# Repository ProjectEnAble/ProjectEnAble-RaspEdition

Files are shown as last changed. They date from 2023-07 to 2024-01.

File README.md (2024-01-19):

# Project: EnAble RPi Edition
   

# Releases 
|Version | Supported |
| --- | --- |
| v4 | IN DEV |
| v3.1.0 - Beta | :white_check_mark: |

# About
Project: EnAble is an open source prosthetic system and design created by Jeron Osguthorpe with hopes to help make the world more accessible. Project: EnAble uses a series of sensors, motors and micro computers (either RPi or Arduino) in order to control customizable
prosthetic devices. Learn more at [projectenable.org](http://projectenable.org).

# CHANGE LOGS

8.30.21 <br>
index.py is created to test the touch sensors. The touch sensors were purchased off of Amazon for 10 of them for about $8. The serial number for the sensors is TTP223 Sensor Module. The sensor module successfully works with the Raspbery Pi 3B+ 

8.31.21 <br>
motors.py, microbit.py, motorspy2.py files were all crated to test certain funciton (look in directory). Remington came over to help program the sensors and the motors. Before he came over, I got all the sensors working and got it so that if the sensor goes off the motors move. We changed it with the help of Rem to make it so that it is now when the sensor is pressed the motor stops. All of this  is contained in motorspy2.py. We are trying to make it so that and "or" statement inside a while statement works. 

9.1.21 <br>
motorspy2.py alteration. Fixed the problem with getting both the sensors to stop the motor. Did this by changing it form an "or" statement to an "and" statement. For some reason, this works.

9.2.21 <br>
Today we had science research because it is a Thurday. I realized in class that I only have 26 avaiable pins for the sensors and the motors at the same time. So I decided to put two sensors into one pin becasue as long as it can send an input to the raspberry pi, it should work. I have decided that I am just going to stick with the Raspberry Pi an the Micro:bit because I really don't want to have to convert everything from Python into Micro:Python becasue honestly that is just a pain. Everthing has been assigned its new pins and they are all contained inside of the new file that I made.

9.2.21 <br>
fixed a couple of spelling mistakes in README.MD. I did this mostly to see if I can use git and github correctly, before I make any big changes to the code.

9.2.21 <br>
Just barely added a bunch of Micro:Bit Serial codes. Here is the list 
Shake = 1 
Logo up = 2
Logo Down = 3
Screen Down = 4
Screen Up = 5
Tilt Left = 6
Tilt Right = 7
Freefall = 8
3G = 9
6G = 10
8G = 11 
A = 12
B = 13 
AB = 14 

12.14.2021 <br>
Changed the motors around in the code and fixed the sleep problem. The entire hand is now assembled, Just have to figure out where I want to put the motors. Other than that the project is pretty much done. It is supposed to be done by 12.16.2021...so I really need to hurry, but it should be all fine. Hopefully Rem can fix the code and get it to me soon. I also uploaded a "main.py" this is now the new main file. 

6.18.2022 <br>
As of June 18th of 2022, this is the final last edit of Project: EnAble v2.0. Project: EnAble v3.0 will now commence including the new forms for the science fairs that the project will be competing in, including the many different forms of the project. Past versions will be avaible in their respective folders. Thanks to everyone who was and is supporting me with this project, we ended up winning First Place in our local science fair, The Air Force award as well as the chance to go to Atlanta, Georgia for the International Science and Engineering Fair (ISEF 2022)!  

6.18.2022 - B <br>
As of June 18th of 2022, the forms for the 2023 year of the project have now been uploaded. The project goes from May 16th 2022 to whenever finished (must be before May 16th 2023). The research plan has also been uploaded for the 2023 project. The 2023 project is refered to as Project: EnAble v3.0. The number after the decimal will change later on in version notes, but the overall project for the year will be refereed to as "Project: EnAble v3.0". The project this year has now been completely opened up to OPEN SOURCE. Anyone can use the files within this project as long as they are following the licenses provided (see LICENCES). All forms and information regarding v1.0 are under the year "2021" however, the files are missing. This project is competing for the International Science and Engineering Fair under Jeron Osguthorpe. Please see more info under v3.0 release notes when it is released. License notes have been updated for the 2023 year. "Project: EnAble is officially licensed with Copyright under the "GNU LESSER GENERAL PUBLIC LICENSE Version 2.1"

6.19.2022 <br>
As of June 19th of 2022, Project: EnAble v3.0 has started production. See the todo list in the "Projects" tab to see what we are doing for Project: EnAble v3.0 at the moment. 

7.24.2022 <br>
Been a while since we have updated the chagne logs. As of right now, we are in the 3D design and printing of the development of Project: EnAble v3.0. Soon hereafter we will have the Gauntlet finished. After that, we will work on the development of the palm, and then the fingers. The Philanges being used this year are going to be an altered design of the philagnes used in the Cyborg Arm by Creighton University, also the philagnes used in v2.0 of Project: EnAble. Hopefully, we will be able to get the Raspberry Pi version of everything up and printed. The only deifference between the Raspberry Pi version and the Arduino version in terms of the phiscial 3D Printed hand, is the Gauntlet. The Gauntlet will be accomondated for the Arduino, however, should not look much different. Thanks for all your support, it is greatly appreciated. Check out our twitter account at http://twitter.com/proj_enable and at our Webstie at http://projectenable.org. To give suggestions, ask questions or anything else, please check our discussions page or email me at jeronosg@outlook.com. If you would like to donate, please see our donations links. If you would like to see how far we are in development, please see our projects page. Again, thanks, and we will keep you updated. 

8.15.2022 <br>
Development of 3D Designs for a Hand for the Project:EnAble v3.0 open source system is on pause. However, development of the Program of Project:EnAble v3.0 has now started and should have the main release finished in a week or so for Raspberry Pi. Development for Arduino version has not started yet. Check out the discusssion and projects tab for more information. 

9.14.2022 <br>
Development has continued. At the moment, basic bugs in the "v3.0" file in the Beta version of Project: EnAble v3.0 have been fixed. Development will stay on pause with code for the next big while I once again, continue to work on the design of the hand. The two main designs that I am having trouble with are the Gauntlet, and the Palm. If you have any suggessions of what I can do with anything, please either message me, visit the discussions tab, make an issue, or tag me on twitter. Thanks. 

9.16.2022 - A <br>
Development of Project: EnAble v3.0.02 - BETA has begun. Sadly, the continuation of the design of the gauntlet has not. I should be getting to that later (as in later today). Project: EnAble v3.0.02 - BETA and above will be using a licensing service offered by Cryptolens. Becasue our project aims to be affordable and open source, the licenses will be free. You will have to request a license however in order to use the program. This is to try to eliminate as much piracy as possible. I am aware that there are ways to get around this by editing the code, I at this point in time am just going to trust the honor system with how far we are with the project. You guys are the best and thank you so much for your suport and your understanding. Let me know if you have any questions, comments, concerns or anything else. 

9.16.2022 - B
Created information.md. information.md gives basic information while programing, such as Micro:Bit information, as well as how to change the project to work with different prosthetics. I also made edits to v3.0.py, making it a bit more cleaned up and organzied. Updated SECURITY.md.

9.17.2022 - 9.18.2022<br>
Updated v3.0.py. Made changes concerning the functions for shaking someones hand and/or canceling the functions. Updated the gauntlet making changes that will fix multiple measurement errors. Also made a YT video containing everything that is/will be new with v3.0.02/03. You can find said video [here](https://youtu.be/PkbhiCFiDQM).

12.10.2022<br>
I know that it has been a while since I have updated this. I apologize for that. In terms of official releases on the project, you can see more in the project history. You can also find out more by visiting our [Twitter Page](http://twitter.com/Proj_EnAble).

1.23.2023<br>
As of today, v3.0.03-BETA is released along side the [YouTube Video](https://www.youtube.com/watch?v=dp4VP448C9U). This is the final BETA release of Project: EnAble v3.0 before the official release. The official release will be released towards the end of Febuary to the beginning of March. If you have any questions, comments or concersn please see the contact information above. If you would like ot know more of Project: EnAble v3.0.03-BETA see the the release under "RELEASES". Thanks for all your support.

3.7.2023<br>
As of today, v3.0.0 is released. This is the official release of Project: EnAble v3.0. If you have any questions, comments or concersn please see the contact information above. If you would like ot know more of Project: EnAble v3.0.0 see the the release under "RELEASES". Thanks for all your support.

5.4.2023 <br>
Bluetooth Support is now added! Now you can use the official Android Project: EnAble app (releasing in late May 2023), to control the sensitivity of the prosthetic devies(s). *NOTE: This is only for Raspberry Pi Edition*. Setting up bluetooth suppport can be found in the information.md file. This contains all the information you need to set up your device. The official Android app will be relased along with Project: EnAble v3.1.0 - Beta in late May of 2023. Expect some crazy new featuers as well as custom sensitivity and user profiles! If you would like to learn more of how this was created, check out the YouTube Channel [Coding Tricks](http://youtube.com/codingtricks). Thank you all for your support!  

6.7.2023<br>
Update on everything. We will be presenting at a tech conference in Chicago in late June. For this tech conference we will be presenting the Arduino v3.1.0 - Beta version of the project. As of today, this version has not been officially released, but it will be in the upcoming weeks. 

7.10.2023<br>
Update again. Chicago was a success! Thank you to all those who have been supporting me and the project thorugh this journey! I am happy to announcethat we will be changing the repositories for the project up a bit. Releasing later today will be two different repositories, one of which will be the Raspberry Pi repository (releasing with v3.1.0 - Beta), and the other will be the Arduino repository (releasing with v3.1.0a - Beta). As with these versions, the official Android App for the Raspberry Pi version can be found at the official website, [projectenable.org](http://projectenable.org). Thanks again for all your support. 

7.10.2023 - B<br>
As another announcemnt, Project: EnAble v2.0 - Final is no longer supported and will be disapearing along with the old repository. 

1.18.2024 <br>
Hello everyone, we haven't updated the Change Logs in a while, so there are a few things that I would like to notify you all of. We are now going to be posting changes and updates on Project: EnAble on the official [website](http://projectenable.org) and the official [X/Twitter](http://twitter.com/proj_enable). We are not going to be updating the change logs here any more. There are a lot of changes in the making right now, and we are going to be updating the repositories in the next little bit. We are going to be redoing the entire README.md as well as introducing more upcoming features. For now, if you would like to stay updated with Project: EnAble, please visit the [official website](http://projectenable.org).

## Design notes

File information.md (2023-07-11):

# Extra Code Information for Project: EnAble v3.0

Here is some extra information about the code contained in v3.0.py. This is information such as [Micro:Bit](https://microbit.org) serial data code, and other related code. 

## Micro:Bit
### Serial Data Codes
B'1' = SHAKE

B'2' = LOGO UP

B'3' = LOGO DOWN

B'4' = SCREEN DOWN

B'5' = SCREEN UP

B'6' = TILT LEFT

B'7' = TILT RIGHT

B'8' = FREEFALL 

B'9' = 3G

B'10' = 6G 

B'11' = 8G

B'12' = BUTTON A

B'13' = BUTTON B

B'14' = BUTTONS AB 

## Connecting Pins
### Servo Motors
Index Finger: 5
Middle Finger: 6
Ring Finger: 13
Pinky Finger: 19
Thumb: 26

### FSR Sensors
CLK: 12
MISO: 16
MOSI: 20
CS: 21

## How to Change from Prostheic Hand, to some other Prosthetic Device
### Step 1
For those of you who are creating a prostheic deivce with the software based off Project: EnAble, this is how you would do this. You will want to make a fork of Project: EnAble off of the [GitHub Repository](http://github.com/projectenable/ProjectEnAble-RaspEdition). 

### Step 2
You will want to then ONLY ALTER v3.0.py. You will only alter information after the comment that says, "START OF CODE (CAN EDIT AS YOU WISH)". Because we use a Micro:Bit as our main sensor for the Raspberry Pi version of the project, we will be altering the functions based off the code. 

#### Step 2.1 - Importing Libraries
Make sure that you have all the libraries imported correctly for your project. You will most likely not need more than I have already provided. 

Some you may have to install onto the Raspberry Pi. You can do this by running the following commands: 
##### PIL/Pillow
`sudo apt-get install python3-pip`
`pip3 install pillow`

##### Touchscreen Libraries
`sudo rm -rf LCD-show`
`git clone https://github.com/goodtft/LCD-show.git`
`chmod -R 755 LCD-show`
`cd LCD-show/`
`sudo ./MPI3508-show`

##### Tkinter (may need)
`sudo apt-get install python3-tk`

#### Bluetooth Connectivity (for Project: EnAble Android Application) -- Upcoming Update

PAIR YOUR PHONE TO THE RASPBERRY PI AND DO THE FOLLOWING STEPS

`sudo bluetoothctl`
`connect PHONE_MAC_ADDRESS`
`trust PHONE_MAC_ADDRESS`

NOW EDIT THE FOLLOWING FILE

`sudo nano /lib/systemd/system/bluetooth.service`
add --compat to line "ExecStart=/usr/lib/bluetooth/bluetoothd" 

Should look like: "ExecStart=/usr/lib/bluetooth/bluetoothd --compat"

NOW RECONNECT THE PHONE TO THE RASPBERRY PI

DO THE FOLLOWING STEPS
`sudo nano /etc/rc.local`

Add `sudo rfcomm watch hci0` before the `exit 0` line 

** REBOOT ** 

NOW YOU MAY RUN `test_bluetooth.py` or `bluetooth.py`

As of right now, bluetooth is experimental, it does not seem to like to corroperate with the app, so we may need to give it it's own separate run file. It shouldn't be too difficult but as of right now we are focusing on other things.

##### Other Libraries Used (should already be preinstalled)
`import subprocess`
`from fileinput import close`
`import RPi.GPIO as GPIO`
`import time`
`from time import sleep`
`import os`
`import random`
`import serial`
`import bluetooth`

#### Step 2.2 - Importing Micro:Bit Serial Information
If you are simply connecting the Micro:Bit to the Raspberry Pi via. USB, you will not need to edit this area. Assuming you are running [Raspberry Pi OS](https://www.raspberrypi.com/software/). If you are running off of other software, the "z1port" may or may not need to be changed according to what port you connect. 

#### Step 2.3 - Setting Variables for Sensors and Motors
For this section, I have already entered the variables for pressure sensors for a prosthetic hand, servo motors for a prosthetic hand. If you are using servo motors, then you dont have to change anything else afterwards. If you ARE NOT using servo motors, then you can change the "SETUP SERVO MOTORS" section. 

Overall, you only need to edit the port numbers according to what you assign. This is what I have assigned. 

#### Step 2.4 - Sensitivity
This is a part that you will edit. If you are wanting multiple modes and need to ask the user for input, then you can edit this to the input that you want. 

NOTE! You can also assign buttons if you want to do this instead of asking for input from the user

#### 2.5 - Functions 
This is probably the part that you will alter the most. This is where you will change what happens based off your functions. In my project, I have 3 input modes, "Low, Medium, and High". For each one, I only change when the motors stop based off the amount of pressure gathered by the pressure sensors. If you are not using modes, then you wont need multiple functions. 

Each function does assignments based off the serial data gathered by the Micro:Bit. You will edit what the motors do based off the serial data that you choose. What you see is what I chose for a prosthetic hand. 

#### 2.6 - Calling the Program 
This is where I call the functions based off the sensitvity. If the user enters low, then run low... and so forth. 

If you are not using multiple modes, just call your function. 

### Step 3
Now that you have altered all your code to do what you would like. Please be sure that you a have a license key for the project. I know that this is annoying and that you wont want one, but they are completely free. This is just to avoid piracy of my program/project. Please be respectful of this. 

According to License Requirements, you must keep all the code together. This means, although you are allowed to edit what is in v3.0.py, you CANNOT delete any files or edit what is in other files. 

You must also state somewhere in your code, "Project: EnAble is under Copyright © 2023 Jeron Osguthorpe". I am going off the honor system, I have spent years on this project and I just am hoping that the development community will respect the work that I have done. 

## Prosthetic Hand - What I have Provided
If you are wanting to reporduce the prosthetic hand that I have created, then all the files needed are included. The 3D Printing files are including in the folder "v3.0 3D Files for Prosthetic Hand". All you will need is a License Key (email enable@codingtrickyt.com). 

## Other Information Regarding Project: EnAble
[GitHub Organization Link](http://github.com/projectenable) 

[GitHub Repository Link](http://github.com/projectenable/ProjectEnAble-RaspEdition)

[Project: EnAble Website](http:/projectenable.org)

Contact Email: enable@codingtricksyt.com

[YouTube](http://youtube.com/codingtricks)

[Twitter](http://twitter.com/proj_enable)

[License, Code of Conduct, and Contributing](http://github.com/projectenable/ProjectEnAble-RaspEdition)

[Donate](http://github.com/projectenable)

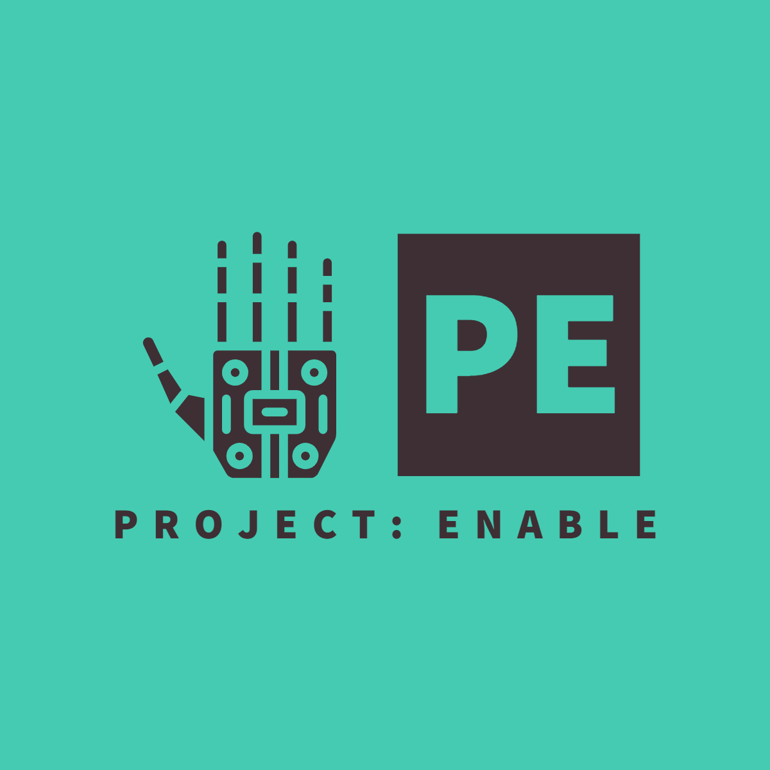
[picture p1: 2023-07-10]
v3.0/images/background.png

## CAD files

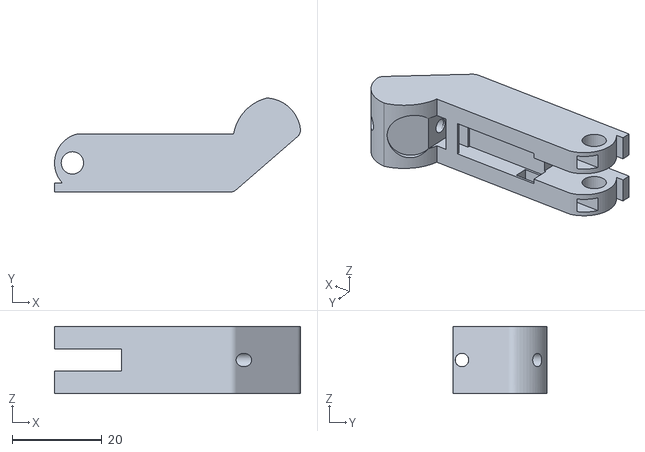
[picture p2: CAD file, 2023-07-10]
v3.0 3D Files for Prosthetic Hand/STL Files/ProjEnAble_Finger.stl
54.9 x 21.0 x 15.0

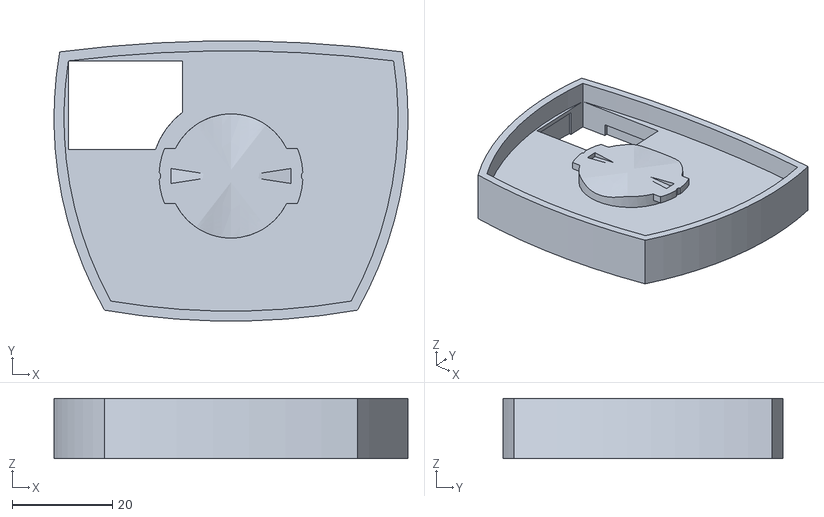
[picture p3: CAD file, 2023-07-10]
v3.0 3D Files for Prosthetic Hand/STL Files/ProjEnAble_MicroBit_Module testing.stl
70.7 x 55.9 x 12.0

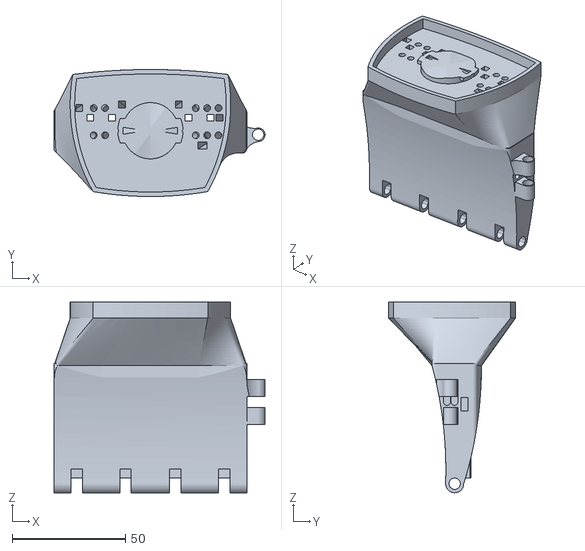
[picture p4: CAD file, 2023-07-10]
v3.0 3D Files for Prosthetic Hand/STL Files/ProjEnAble_Hand.stl
93.0 x 56.0 x 84.0

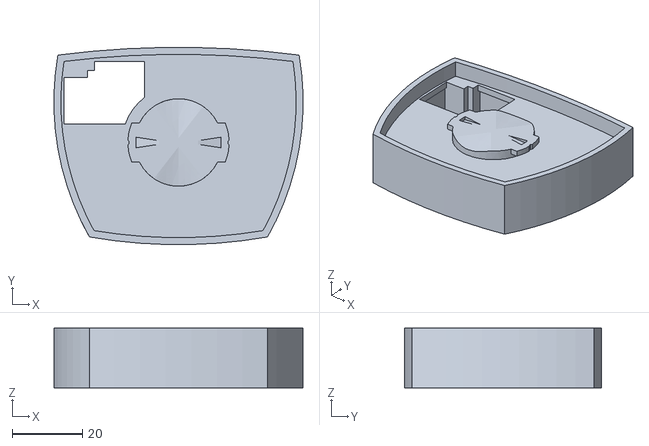
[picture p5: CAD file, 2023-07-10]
v3.0 3D Files for Prosthetic Hand/STL Files/ProjeEnAble_MicroBit_Module.stl
70.7 x 55.9 x 17.0

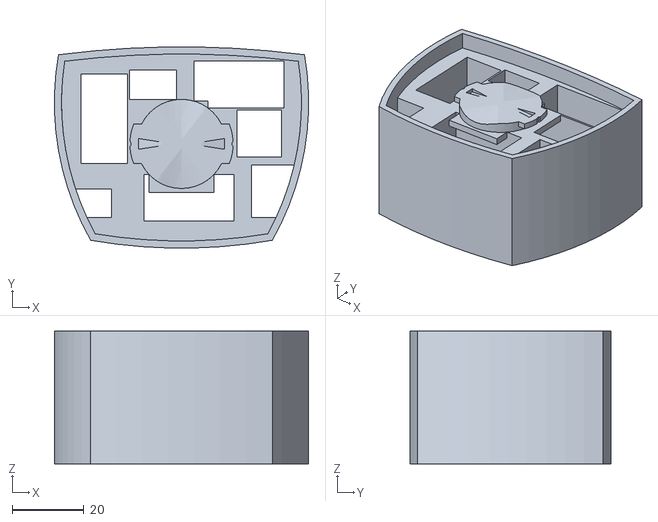
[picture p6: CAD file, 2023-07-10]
v3.0 3D Files for Prosthetic Hand/STL Files/ProjEnAble_Motor_Module.stl
70.7 x 55.9 x 37.0

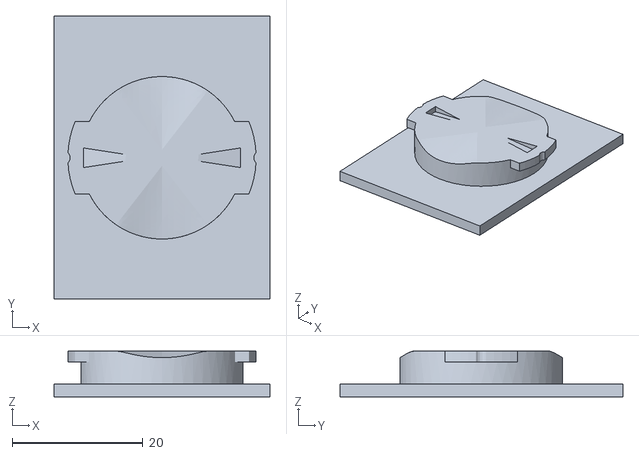
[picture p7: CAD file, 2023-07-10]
v3.0 3D Files for Prosthetic Hand/STL Files/GARMIN_QUARTER-TURN.stl
33.0 x 43.2 x 7.00

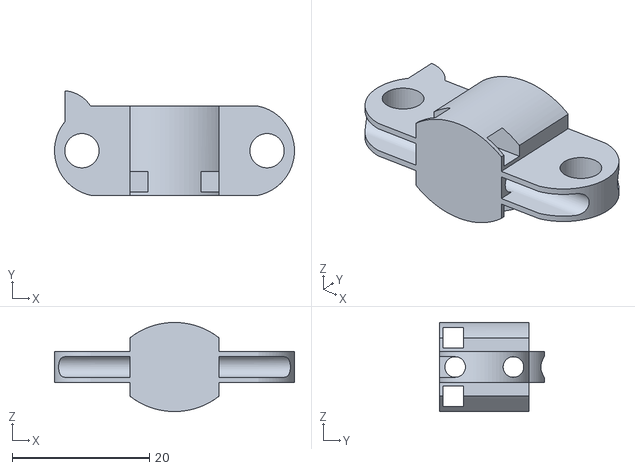
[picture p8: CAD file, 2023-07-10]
v3.0 3D Files for Prosthetic Hand/STL Files/ProjEnAble_Philange.stl
35.0 x 15.2 x 13.0

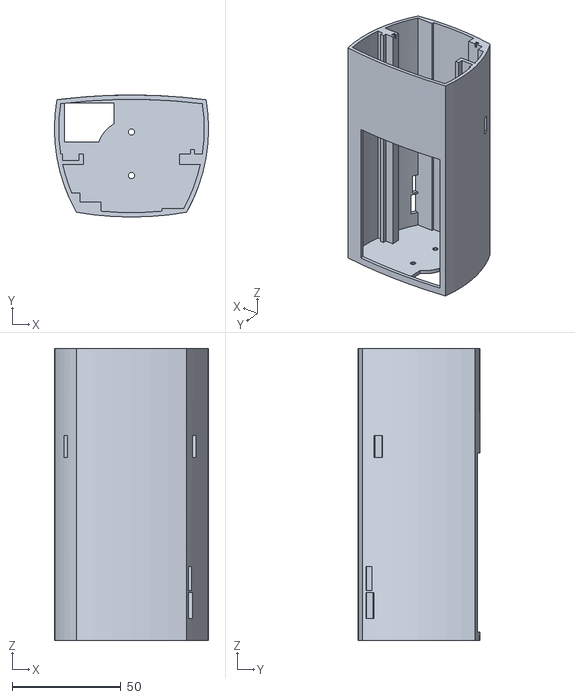
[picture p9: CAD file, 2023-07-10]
v3.0 3D Files for Prosthetic Hand/STL Files/ProjEnAble_RaspPiGaunt.stl
70.8 x 56.0 x 134.0

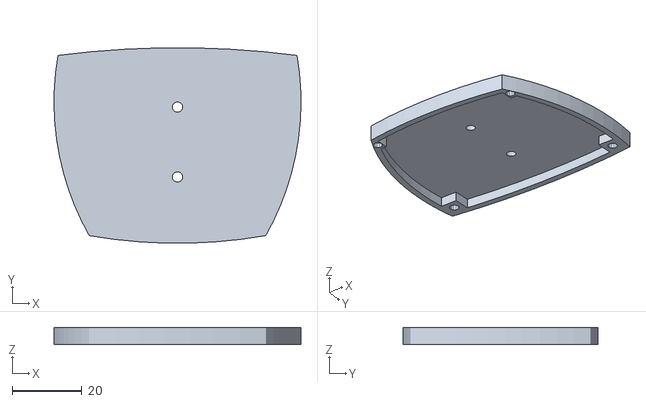
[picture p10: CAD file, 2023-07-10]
v3.0 3D Files for Prosthetic Hand/STL Files/ProjEnAble_Microbit_Cover.stl
70.7 x 55.9 x 5.00

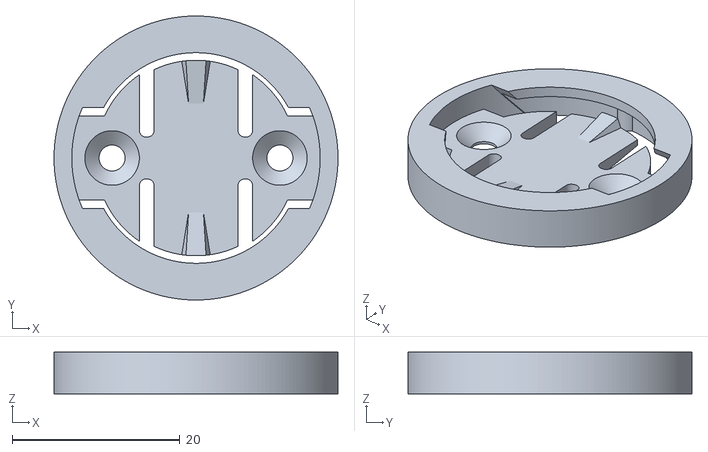
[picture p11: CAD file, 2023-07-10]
v3.0 3D Files for Prosthetic Hand/STL Files/GARMIN_K-EDGE.stl
33.8 x 33.8 x 5.00

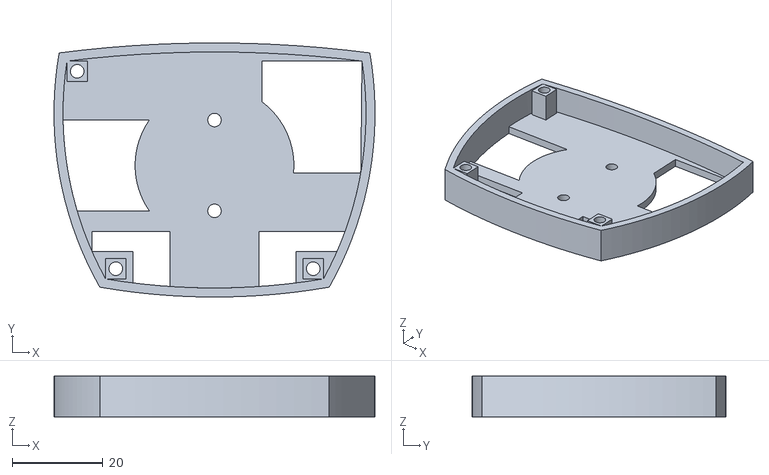
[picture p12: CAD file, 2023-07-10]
v3.0 3D Files for Prosthetic Hand/STL Files/ProjEnAble_Motor_Cover.stl
70.7 x 56.0 x 9.00

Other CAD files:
v3.0 3D Files for Prosthetic Hand/Design Files/Imported Components/GarminQuarterTurn/GarminQuarterTurn.ipt
v3.0 3D Files for Prosthetic Hand/Design Files/Imported Components/GarminQuarterTurn/OldVersions/GarminQuarterTurn.0001.ipt
v3.0 3D Files for Prosthetic Hand/Design Files/ProjEnAble_Finger.ipt
v3.0 3D Files for Prosthetic Hand/Design Files/ProjEnAble_Finger_Philange.ipt
v3.0 3D Files for Prosthetic Hand/Design Files/ProjEnAble_Hand.ipt
v3.0 3D Files for Prosthetic Hand/Design Files/ProjEnAble_MicroBit_Module Test.ipt
v3.0 3D Files for Prosthetic Hand/Design Files/ProjEnAble_MicroBit_Module.ipt
v3.0 3D Files for Prosthetic Hand/Design Files/ProjEnAble_Microbit_Cover.ipt
v3.0 3D Files for Prosthetic Hand/Design Files/ProjEnAble_Motor_Cover.ipt
v3.0 3D Files for Prosthetic Hand/Design Files/ProjEnAble_Motor_Module.ipt
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

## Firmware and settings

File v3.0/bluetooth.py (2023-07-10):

"""
Welcome to Project:EnAble v3.0
Project:EnAble is under Copyright © 2023 Jeron Osguthorpe

Project: EnAble
Author: Jeron Osguthorpe
Version: v3.1.0 - Beta

BASIC INFORMATION REGARDING PROJECT: ENABLE
Git Hub Organization Link: https://github.com/projectenable
Git Hub Repository Link: https://github.com/projectenable/Project-Enable
Website: https://enable.codingtricksyt.com
Email: enable@codingtricksyt.com
YouTube: https://youtube.com/codingtricks
Twitter: https://twitter.com/proj_enable
License, Code of Conduct, and Contributing: https://github.com/projectenable/Project-Enable
Donate: https://enable.codingtricksyt.com/

NOTE: This code is experimental and may not work. 

"""

# IMPORT LIBRARIES
import serial
import v3
 
# SETTING UP THE SERIAL PORT
ser = serial.Serial('/dev/rfcomm0')
print("Bluetooth Ready")
print("Use the Project: EnAble App To Control Sensitivity")
while True:
    x = ser.read(1)
    if x == b'1':
        v3.start(50)
    elif x == b'2':
        v3.start(62)
    elif x == b'3':
        v3.start(76)
    elif x == b'4':
        v3.start(89)
    elif x == b'5':
        v3.start(100)
    elif x == b'6':
        v3.start(115)
    elif x == b'7':
        v3.start(128)
    elif x == b'8':
        v3.start(141)
    elif x == b'9':
        v3.start(150)



"""
Project: EnAble© is under Copyright 2023 by Jeron Osguthorpe. Though the project is open source, taking all 
credit for works is not. Though you are allowed to use the code for your own projects, you are not allowed to
take credit for the code. If you would like help with the code, please contact Jeron Osguthorpe. Contact 
information can be found on the Project: EnAble© website and GitHub repository/organization.
"""

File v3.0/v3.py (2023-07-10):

"""
Welcome to Project:EnAble v3.0
Project:EnAble is under Copyright © 2023 Jeron Osguthorpe

Project: EnAble
Author: Jeron Osguthorpe
Version: v3.1.0 - Beta

BASIC INFORMATION REGARDING PROJECT: ENABLE
Git Hub Organization Link: https://github.com/projectenable
Git Hub Repository Link: https://github.com/projectenable/Project-Enable
Website: https://enable.codingtricksyt.com
Email: enable@codingtricksyt.com
YouTube: https://youtube.com/codingtricks
Twitter: https://twitter.com/proj_enable
License, Code of Conduct, and Contributing: https://github.com/projectenable/Project-Enable
Donate: https://enable.codingtricksyt.com/

ChatGPT Involment: ChatGPT was used to help create part of the project. Among ChatGPT, 
Copilot was also used to help create this part of the project. ChatGPT is a project by OpenAI. 
Copilot is a project by OpenAI and GitHub. Both projects are under the MIT License.

Total Project Lines of Code: 1137

"""
# IMPORTING LIBRARIES
from fileinput import close
from multiprocessing.resource_sharer import stop 
import RPi.GPIO as GPIO 
import time
from time import sleep
import os
import random
import serial

# SETTING MODES
GPIO.setmode(GPIO.BCM)

# IMPORT MICROBIT SERIAL INFORMATION
z1baudrate = 115200
z1port = '/dev/ttyACM0' # This is the port that the microbit is connected to
z1serial = serial.Serial(port=z1port, baudrate=z1baudrate)
z1serial.timeout = 2

# SERVO MOTORS
GPIO.setup(5, GPIO.OUT) # index finger
GPIO.setup(6, GPIO.OUT) # middle finger
GPIO.setup(13, GPIO.OUT) # ring finger
GPIO.setup(19, GPIO.OUT) # pinky finger
GPIO.setup(26, GPIO.OUT) # thumb

# Initialize PWM on all servo pins
index_servo = GPIO.PWM(5, 50) # index finger
index_servo.start(0) # Initialize Index Servo
middle_servo = GPIO.PWM(6, 50) # middle finger
middle_servo.start(0) # Initialize Middle Servo
ring_servo = GPIO.PWM(13, 50) # ring finger
ring_servo.start(0) # Initialize Ring Servo
pinky_servo = GPIO.PWM(19, 50) # pinky finger
pinky_servo.start(0) # Initialize Pinky Servo
thumb_servo = GPIO.PWM(26, 50) # thumb
thumb_servo.start(0) # Initialize Thumb Servo



# PRESSURE SENSORS
# Pin Definitions
CLK = 12
MISO = 16
MOSI = 20
CS = 21

# Set Up GPIO using BCM numbering
GPIO.setup(CLK, GPIO.OUT)
GPIO.setup(MISO, GPIO.IN)
GPIO.setup(MOSI, GPIO.OUT)
GPIO.setup(CS, GPIO.OUT)

# Function to read data from ADC using software SPI
def read_adc(channel):
    # Chip Select Signal
    GPIO.output(CS, GPIO.HIGH)
    GPIO.output(CS, GPIO.LOW)

    # Start Bit
    GPIO.output(MOSI, GPIO.HIGH)
    GPIO.output(CLK, GPIO.HIGH)
    GPIO.output(CLK, GPIO.LOW)

    # Channel Selection
    for i in range(3):
        if (channel & (1 << i)) == 0:
            GPIO.output(MOSI, GPIO.LOW)
        else:
            GPIO.output(MOSI, GPIO.HIGH)
        GPIO.output(CLK, GPIO.HIGH)
        GPIO.output(CLK, GPIO.LOW)
    
    # Dummy Bit
    GPIO.output(MOSI, GPIO.LOW)
    GPIO.output(CLK, GPIO.HIGH)
    GPIO.output(CLK, GPIO.LOW)

    # Read Data
    data = 0
    for i in range(11):
        GPIO.output(CLK, GPIO.HIGH)
        if GPIO.input(MISO) == GPIO.HIGH:
            data |= 1 << (10 - i)
        GPIO.output(CLK, GPIO.LOW)
    
    # Chip Select Signal
    GPIO.output(CS, GPIO.HIGH)

    return data

# DEFINE SENSITIVITY THRESHOLDS
low_threshold = 50
medium_threshold = 100
high_threshold = 150

# CANCEL ALL FUNCTION
def cancel_all():
    print("Stopping All")
    stopall = True
    GPIO.cleanup()

#  MAIN PROGRAM
def start(threshold):
    global stopall
    stopall = False
    while not stopall:

        # READ DATA

        # Add Microbit Data
        size = z1serial.inWaiting()
        data = z1serial.read(size)

        # Globalize Variables
        global index_pressure_sensor
        global middle_pressure_sensor
        global ring_pressure_sensor
        global pinky_pressure_sensor
        global thumb_pressure_sensor

        # Read Pressure Sensor Data
        index_pressure_sensor = read_adc(0)
        middle_pressure_sensor = read_adc(1)
        ring_pressure_sensor = read_adc(2)
        pinky_pressure_sensor = read_adc(3)
        thumb_pressure_sensor = read_adc(4)

        # Print Pressure Sensor Data
        print("Index Pressure Sensor: ", index_pressure_sensor)
        print("Middle Pressure Sensor: ", middle_pressure_sensor)
        print("Ring Pressure Sensor: ", ring_pressure_sensor)
        print("Pinky Pressure Sensor: ", pinky_pressure_sensor)
        print("Thumb Pressure Sensor: ", thumb_pressure_sensor)
        time.sleep(0.5)

        # Move Fingers
        """
        We are now to where most of the editing will be happening. This is where you will edit what the program does
        when the Microbit sends serial data. You can see what each serial data code is by looking at information.md.
        """
        if data == b'1':
            stop = False
            while not stop:
                if index_pressure_sensor > threshold:
                    index_servo.ChangeDutyCycle.stop()
                if middle_pressure_sensor > threshold:
                    middle_servo.ChangeDutyCycle.stop()
                if ring_pressure_sensor > threshold:
                    ring_servo.ChangeDutyCycle.stop()
                if pinky_pressure_sensor > threshold:
                    pinky_servo.ChangeDutyCycle.stop()
                if thumb_pressure_sensor > threshold:
                    thumb_servo.ChangeDutyCycle.stop()
                print("One")
                stop = True

                # Finish
                if index_pressure_sensor > threshold and middle_pressure_sensor > threshold and ring_pressure_sensor > threshold and pinky_pressure_sensor > threshold and thumb_pressure_sensor > threshold:
                    stop = True
        
        if data == b'12':
            print("Shake Hand")
            stop = False
            i = 5
            while not stop:
                # Thresholds
                if index_pressure_sensor > threshold:
                    index_servo.ChangeDutyCycle.stop()
                if middle_pressure_sensor > threshold:
                    middle_servo.ChangeDutyCycle.stop()
                if ring_pressure_sensor > threshold:
                    ring_servo.ChangeDutyCycle.stop()
                if pinky_pressure_sensor > threshold:
                    pinky_servo.ChangeDutyCycle.stop()
                if thumb_pressure_sensor > threshold:
                    thumb_servo.ChangeDutyCycle.stop()
                
                # Shake Hand
                index_servo.ChangeDutyCycle(i)
                middle_servo.ChangeDutyCycle(i)
                ring_servo.ChangeDutyCycle(i)
                pinky_servo.ChangeDutyCycle(i)
                thumb_servo.ChangeDutyCycle(i)
                sleep(0.25)
                print("Two Value: ", i)
                i += 2.5
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
